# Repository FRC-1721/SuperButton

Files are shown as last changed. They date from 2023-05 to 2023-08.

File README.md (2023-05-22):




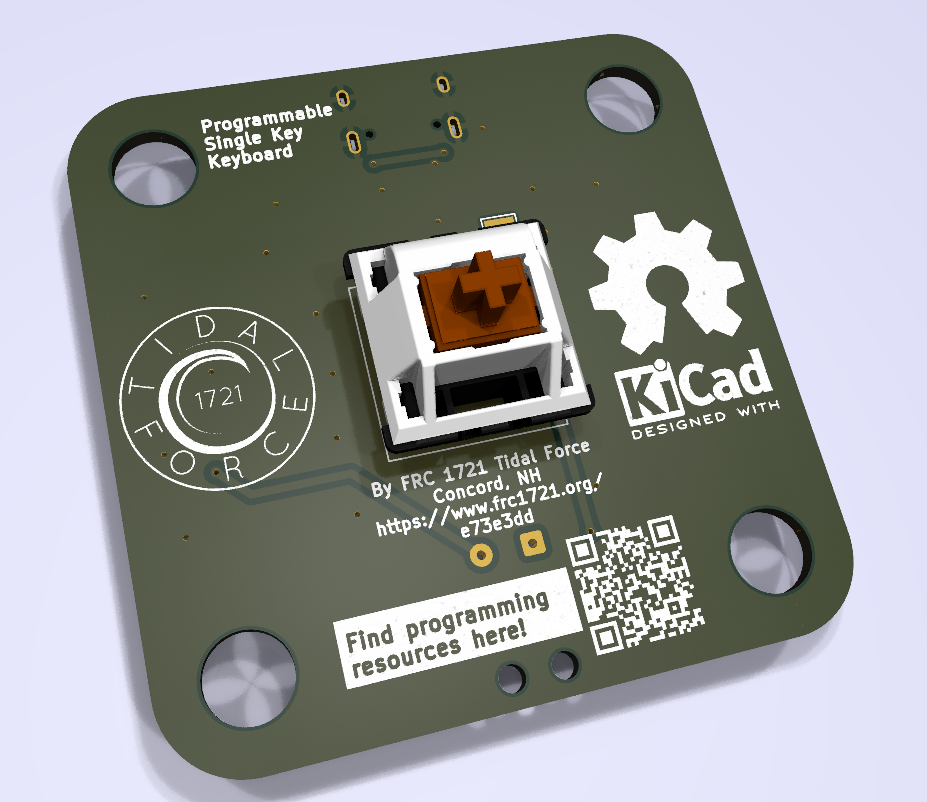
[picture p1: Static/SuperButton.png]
The Superbutton!


# Welcome!

# Getting Started!

Clone the repo with submodules!

```shell
git clone --recurse-submodules https://github.com/FRC-1721/SuperButton.git
```

## Init Submodules

Some libraries and resources are included as submodules, run the following
command to initialize them before opening the main sch

(If you get a missing library error, make sure to do this)

```shell
git submodule update --init --recursive
```

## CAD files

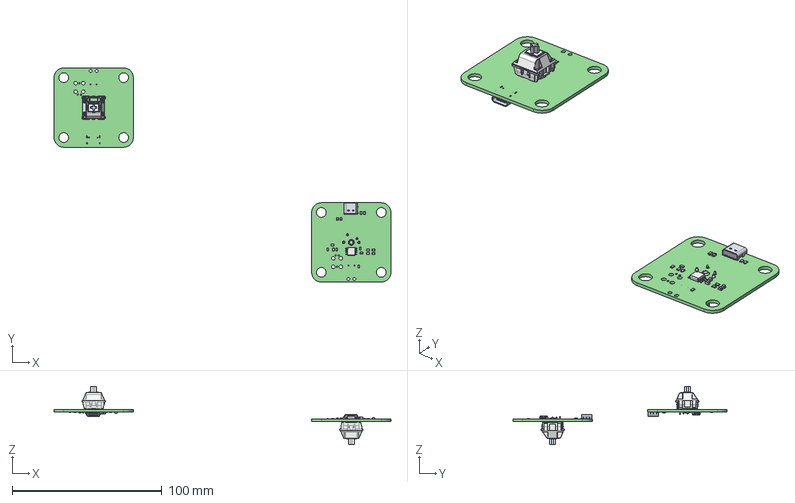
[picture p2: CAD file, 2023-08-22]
CAD/Assembly.FCStd
225.0 x 143.0 x 38.9 mm
tmpvxgqe7ir PCB x 2

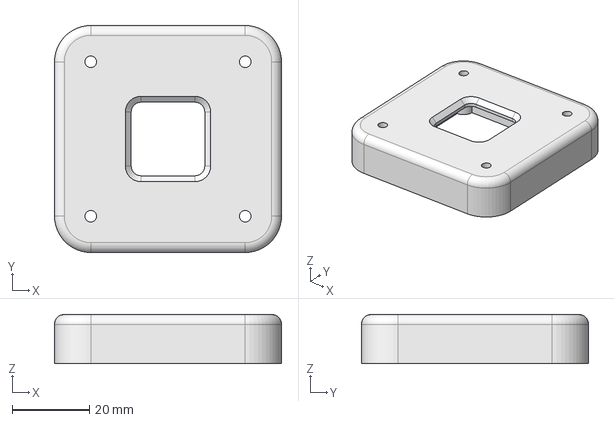
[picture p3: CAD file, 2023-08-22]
CAD/Top.FCStd
58.8 x 58.8 x 12.7 mm

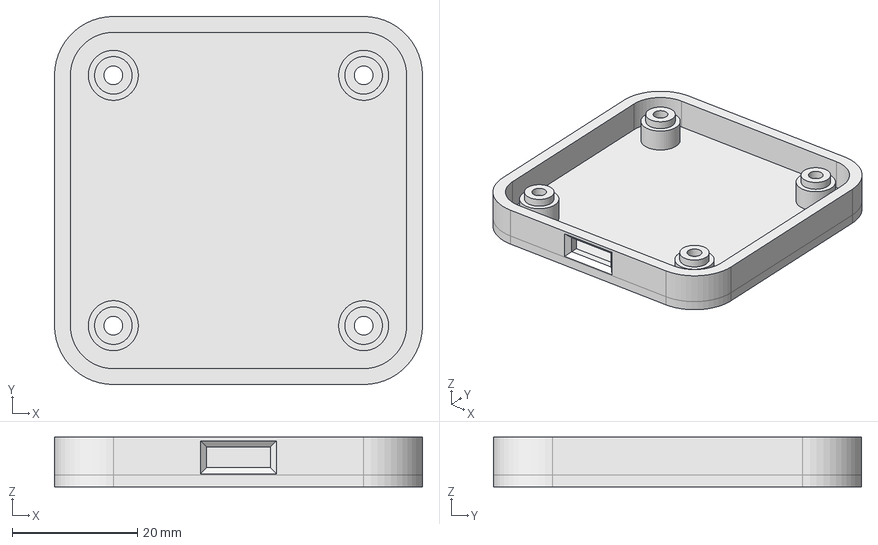
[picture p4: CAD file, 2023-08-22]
CAD/Base.FCStd
58.8 x 58.8 x 7.95 mm

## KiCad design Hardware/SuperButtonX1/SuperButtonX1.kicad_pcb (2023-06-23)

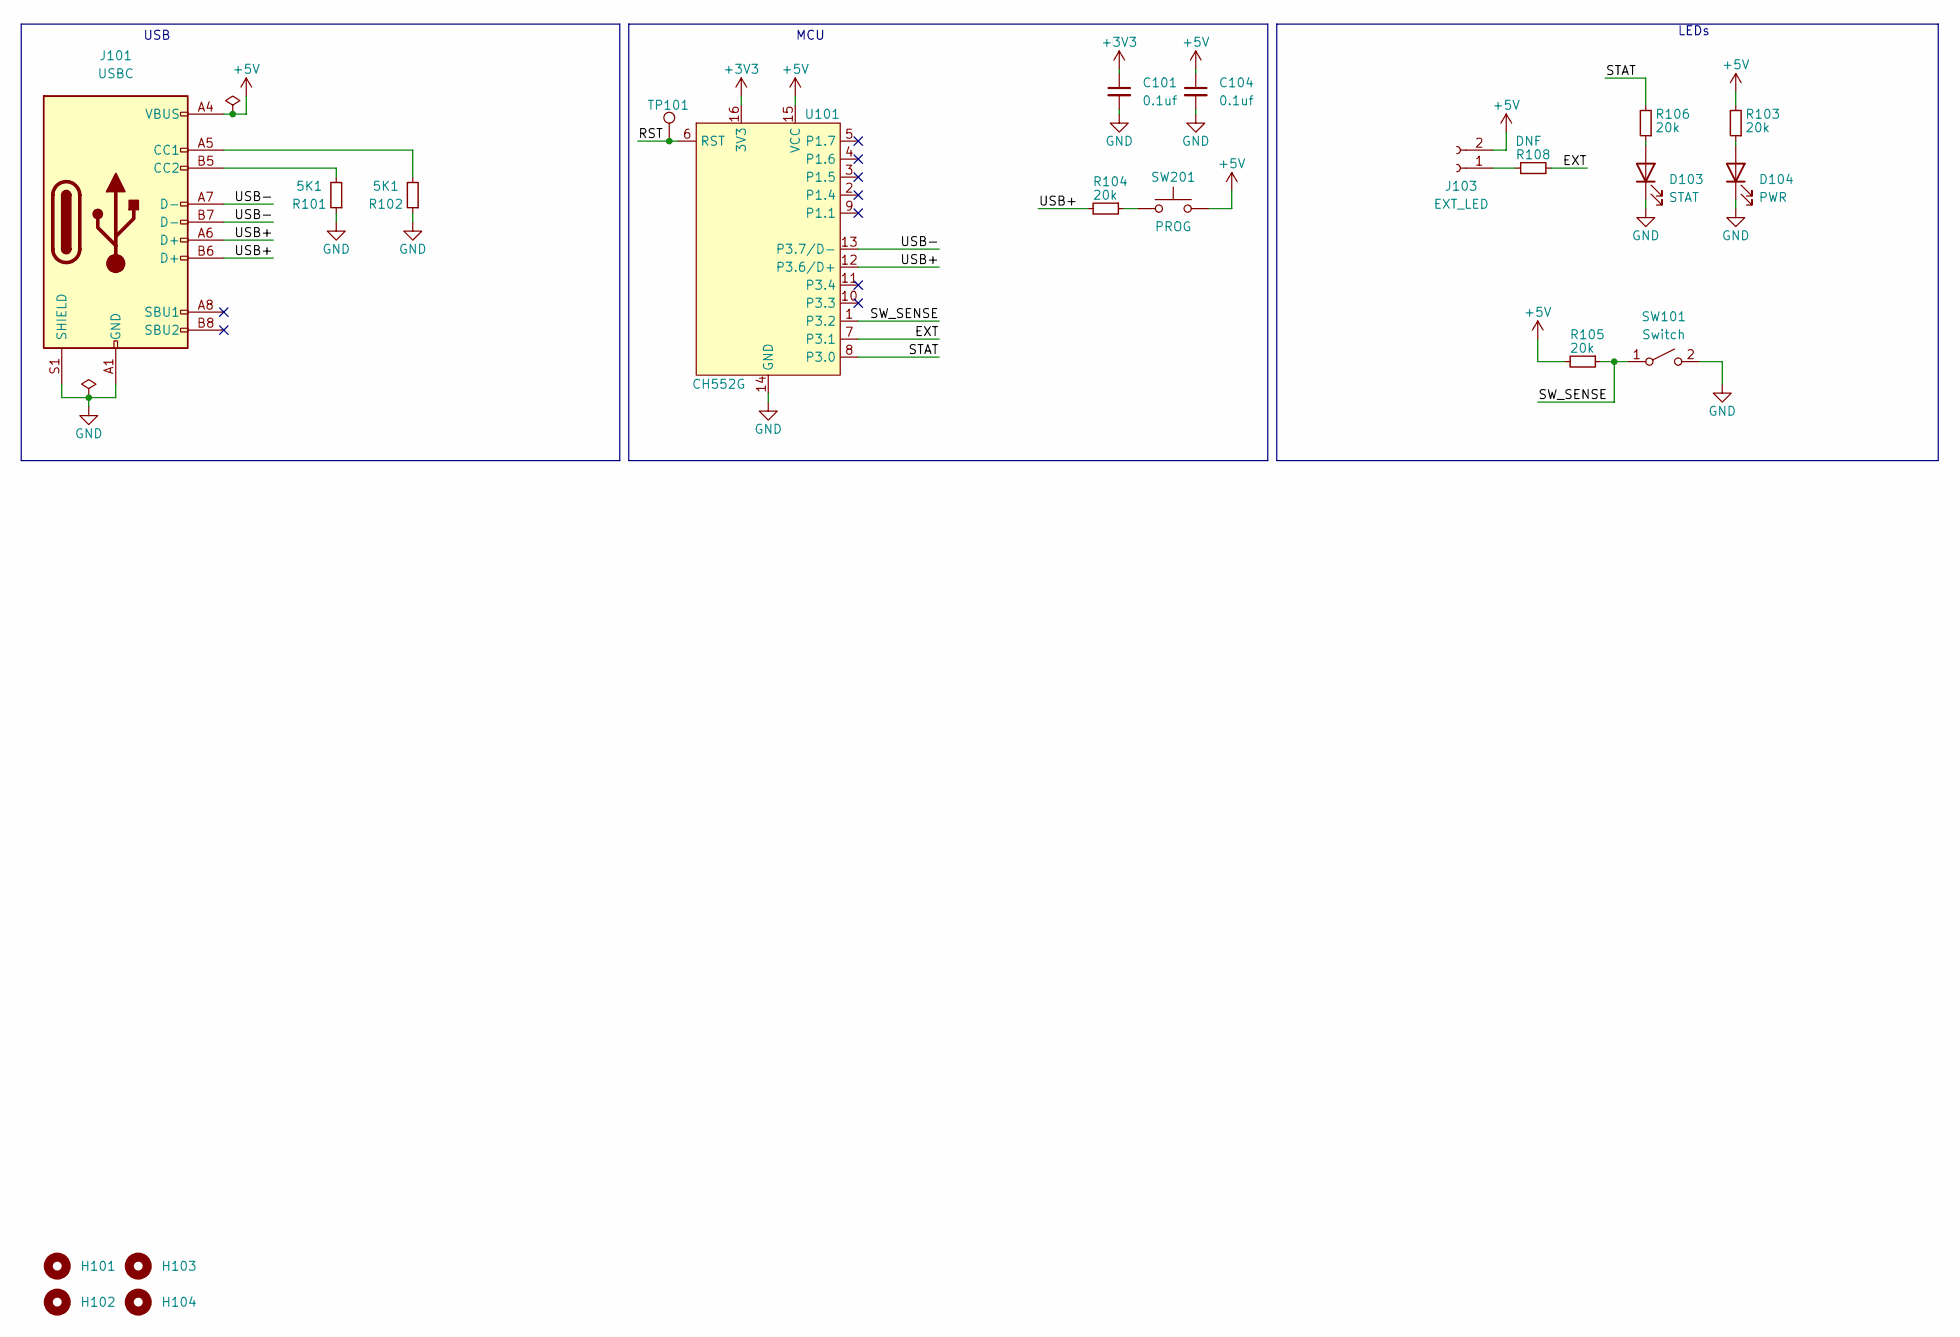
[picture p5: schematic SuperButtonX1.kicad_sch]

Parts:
C101, C104: 0.1uf; C_0805_2012Metric; LCSC# C49678
D103: STAT; LED_0805_2012Metric; LCSC# C84256
D104: PWR; LED_0805_2012Metric; LCSC# C84256
H101, H102, H103, H104: MountingHole; MountingHole_6.5mm
J101: USBC; USB_C_Receptacle_XKB_U262-16XN-4BVC11; LCSC# C319148
J103: EXT_LED; SolderWire-0.15sqmm_1x02_P4mm_D0.5mm_OD1.5mm_Relief
R101, R102: 5K1; R_0805_2012Metric; LCSC# C269748
R103, R104, R105, R106: 20k; R_0805_2012Metric; LCSC# C17606
R108: DNF; R_0805_2012Metric; LCSC# C17606
SW101: Switch; SW_Cherry_MX_PCB
SW201: PROG; SW_SPST_TL3342; LCSC# C318884
TP101: TestPoint; TestPoint_Pad_2.5x2.5mm
U101: CH552G; SOP-16_3.9x9.9mm_P1.27mm; LCSC# C111292

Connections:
+3V3: C101.1, U101.16 (3V3)
+5V: C104.1, J101.A4 (VBUS), J101.A9 (VBUS), J101.B4 (VBUS), J101.B9 (VBUS), J103.2, R103.2, R105.2, U101.15 (VCC); also elsewhere on the board
/EXT: R108.2, U101.7 (P3.1)
/RST: TP101.1, U101.6 (RST)
/STAT: R106.2, U101.8 (P3.0)
/SW_SENSE: R105.1, SW101.1 (A), U101.1 (P3.2)
/USB+: J101.A6 (D+), J101.B6 (D+), R104.2, U101.12 (P3.6/D+)
/USB-: J101.A7 (D-), J101.B7 (D-), U101.13 (P3.7/D-)
GND: C101.2, C104.2, D103.1 (K), D104.1 (K), J101.A1 (GND), J101.A12 (GND), J101.B1 (GND), J101.B12 (GND), J101.S1 (SHIELD), R101.1, R102.1, SW101.2 (B), U101.14 (GND)
unnamed: D103.2 (A), R106.1
unnamed: D104.2 (A), R103.1
unnamed: J101.A5 (CC1), R102.2
unnamed: J101.B5 (CC2), R101.2
unnamed: J103.1, R108.1
unnamed 14: R104.1; also elsewhere on the board

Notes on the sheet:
USB
LEDs
MCU

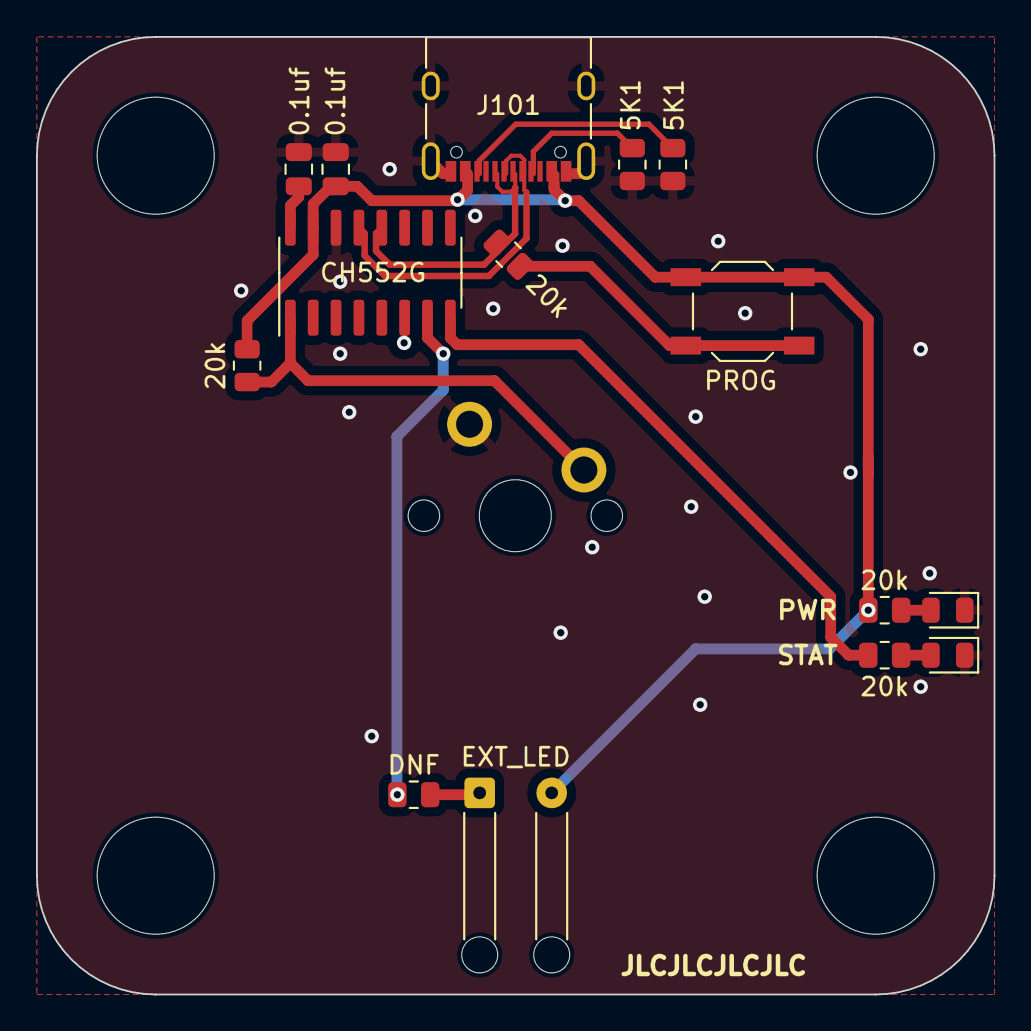
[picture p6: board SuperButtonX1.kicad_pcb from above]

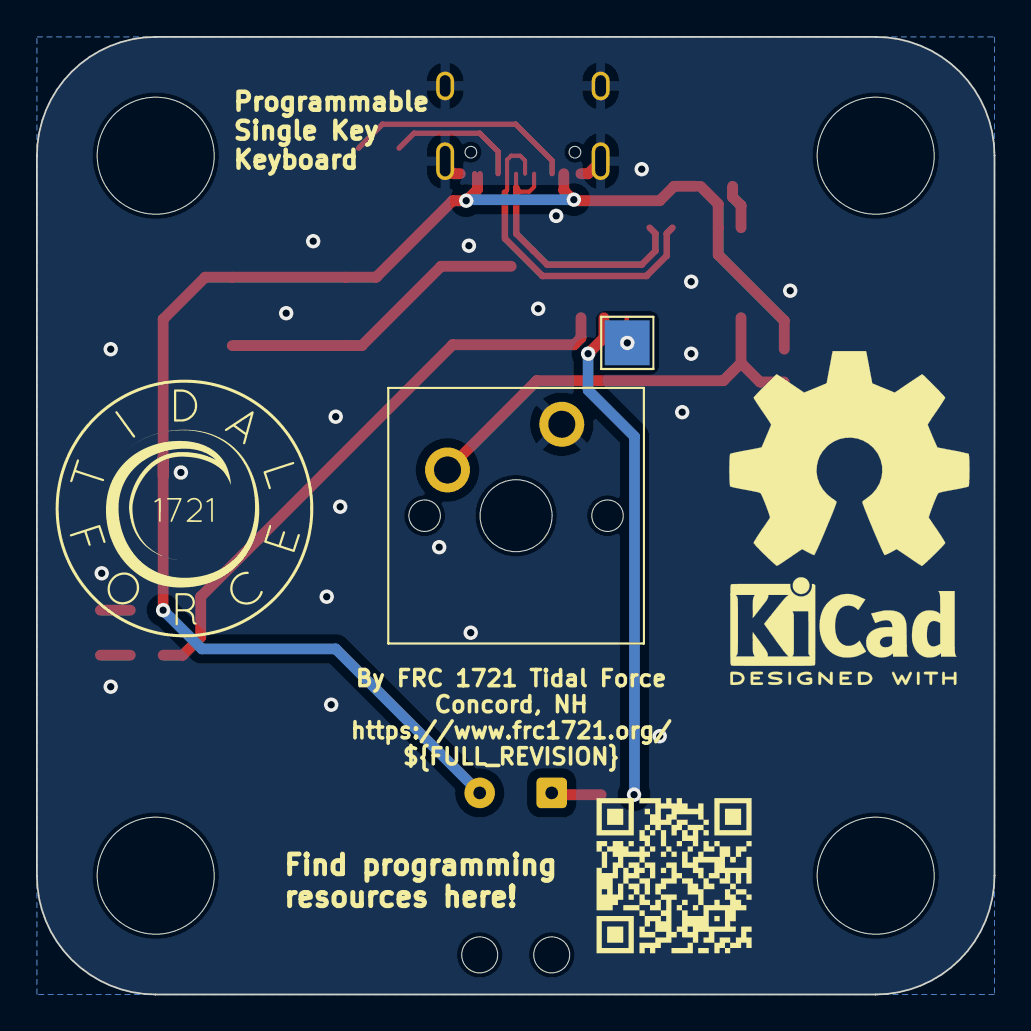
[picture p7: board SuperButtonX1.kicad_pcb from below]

Board: 2 copper layers, 53.2 x 53.2 mm, 21 parts (6 on the bottom side), 15 nets.

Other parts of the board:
SW102: PROG; SW_SPST_TL3342

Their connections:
+5V: SW102.2; also elsewhere on the board
unnamed 14: SW102.1; also elsewhere on the board

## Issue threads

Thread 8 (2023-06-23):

Wrong LCSC Part number for 20k reistors

KenwoodFox, 2023-06-23:
Two issues in here
- Not every resistor **should** be 20k, some should be 2
- The 20k part number is invalid, C17606 is the wrong component (its actually 2.0000 not 20,000)

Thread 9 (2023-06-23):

Text printing issue, misprint on 1721

KenwoodFox, 2023-06-23:
Looks like the 1721 in the middle of the logo is too small to be printed correctly.

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

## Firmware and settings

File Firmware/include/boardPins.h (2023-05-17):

#ifndef _BOARD_PINS_H
#define _BOARD_PINS_H

// LEDs
#define STAT_LED 13

// shift definitions
#define LATCH_PIN 10
#define CLOCK_PIN 9
#define DATA_PIN 8

// Board
#define NUM_SEGMENTS 3

#endif

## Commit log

2023-01-18 Blank project!
    [SuperButton.kicad_pcb, SuperButton.kicad_sch]
2023-05-17 CH552G (#3)
    [Assembly.FCStd, Base.FCStd, SuperButton.kicad_pcb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]
2023-05-22 Feat/Variants (#4)
    [SuperButtonX1.kicad_pcb, SuperButtonX1.kicad_sch, SuperButtonX3.kicad_pcb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]
2023-06-23 Add JLCJLCJLC to boards
    [SuperButtonX1.kicad_pcb, SuperButtonX3.kicad_pcb]
2023-08-22 add single board top
    [Assembly.FCStd, Base.FCStd, Top.FCStd]
